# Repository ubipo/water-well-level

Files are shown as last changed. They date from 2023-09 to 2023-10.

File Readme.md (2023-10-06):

# Water Well Level 🛜📏🪣💦

**Ultrasonic IoT sensor to measure water level in a well**

My dad and I needed a way to ensure the water level in a rain water collection
well doesn't drop too low and that a pump actually uses the water as scheduled.
So, as a fun end-to-end IoT project, I put together a sensor, serverless
backend, and web UI.

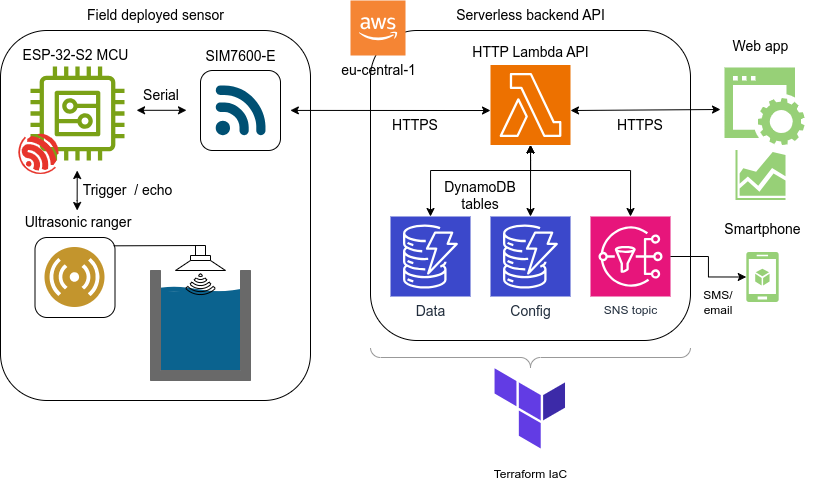
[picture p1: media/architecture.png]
Architecture


## Sensor

The field-deployed sensor uses a
[hc-sr04](https://www.velleman.eu/products/view/?id=463692)-like ultrasonic
ranger to measure the water level from above. The measurements from this are
collected by an [ESP32-S2](https://www.sparkfun.com/products/17743) WiFi microcontroller.
Because we don't - yet - have WiFi available though, I also added a
[SIM7600E](https://simcom.ee/modules/lte/sim7600e/) cellular breakout board with
a prepaid SIM. The microcontroller is programmed in C++ using the
[PlatformIO](https://platformio.org/) toolchain. This entire system is powered by two 2500
mAh @ 3.7 V LiPo
batteries for a battery life of hopefully at least ~3 weeks @ 1
measurement/hour.

## Serverless backend

The sensor periodically sends its measurements and remaining battery capacity to
a serverless HTTPS API deployed to [AWS Lambda](https://aws.amazon.com/lambda/).
The lambda then saves these measurements to a
[DynamoDB](https://aws.amazon.com/dynamodb/) table and notifies an
[SNS](https://aws.amazon.com/sns/) topic for SMS and email notifications. It
also has an endpoint to query the table and to save and retrieve configuration
values. This cloud infrastructure is all defined and deployed as
[Terraform](https://www.terraform.io/) code.

## Web UI

Finally, a [Svelte](https://svelte.dev/) web app hosted on GitHub pages queries the lambda backend and presents the data in a graph using
[Chart.js](https://www.chartjs.org/). The app also allows you to configure the
sensor remotely.

## Images

<figure>
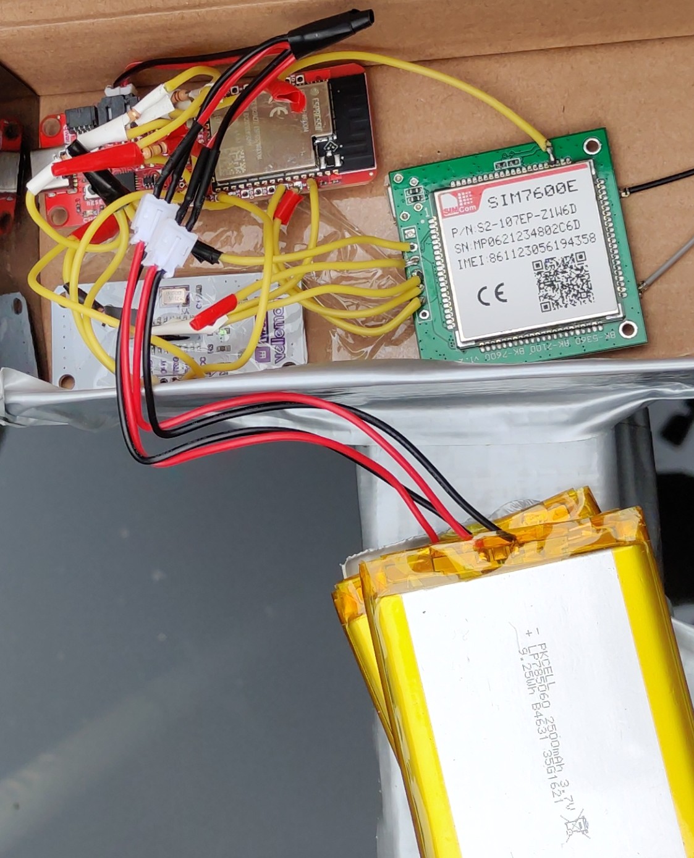
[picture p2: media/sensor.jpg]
Sensor
  
  <figcaption style="text-align: center; font-style: italic;">
    The sensor with white ultrasonic ranger, green SIM7600E cellular breakout board, and red ESP32-S2 microcontroller.
  </figcaption>
</figure>

<figure>
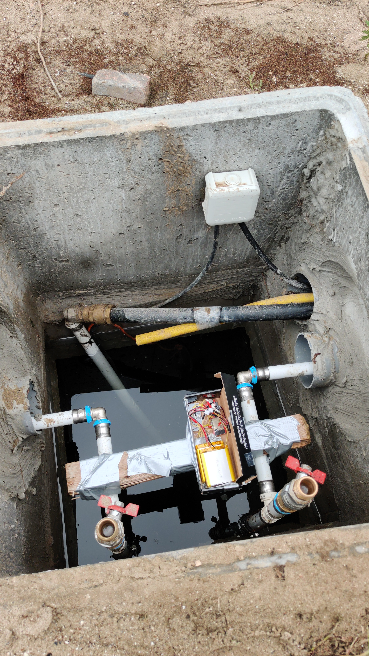
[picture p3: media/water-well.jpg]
Water well
  
  <figcaption style="text-align: center; font-style: italic;">
    The water well with the sensor - for now - attached to pvc pipes.
  </figcaption>
</figure>

<figure>
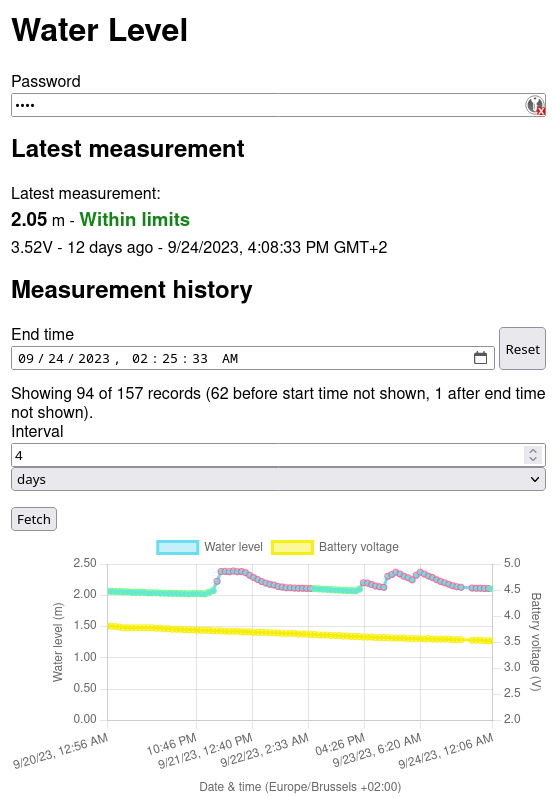
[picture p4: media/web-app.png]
Web app
  
  <figcaption style="text-align: center; font-style: italic;">
    The web app showing the water level and battery voltage over time.
  </figcaption>
</figure>

<figure>
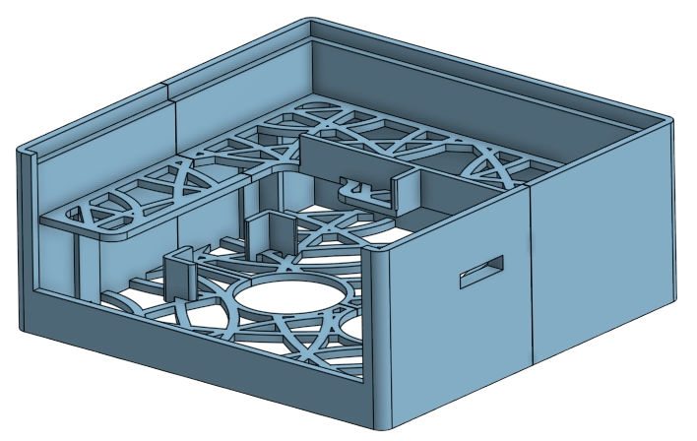
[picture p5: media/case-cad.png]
Case CAD design
  
  <figcaption style="text-align: center; font-style: italic;">
    CAD model of the case for the sensor with snap close tabs. I haven't been able to produce a proper print yet due to bed adhesion issues.
  </figcaption>
</figure>

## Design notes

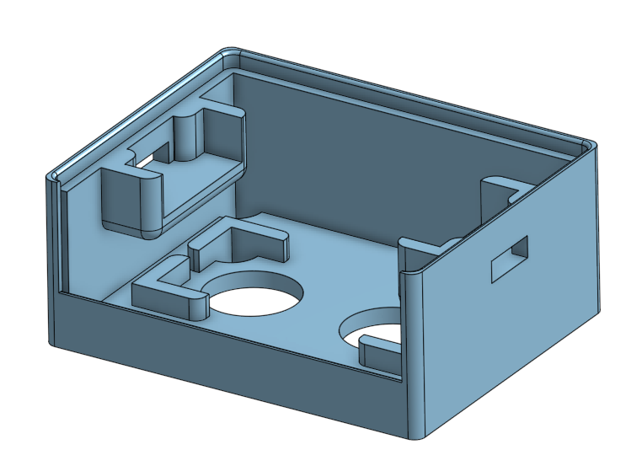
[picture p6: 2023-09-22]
v1-solid/main.png

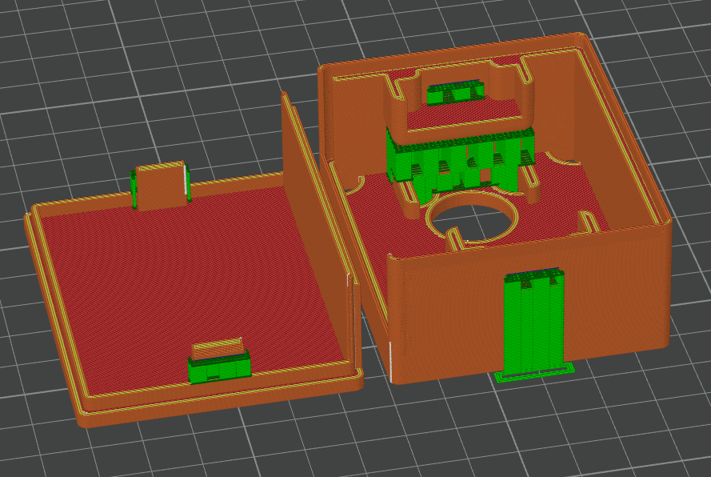
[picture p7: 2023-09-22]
v1-solid/sliced.png

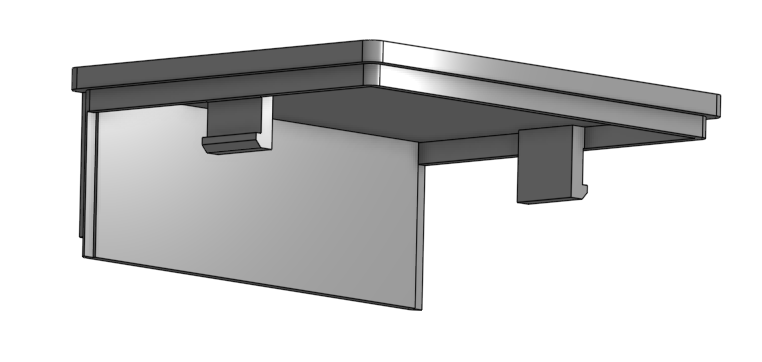
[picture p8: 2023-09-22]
v1-solid/cover.png

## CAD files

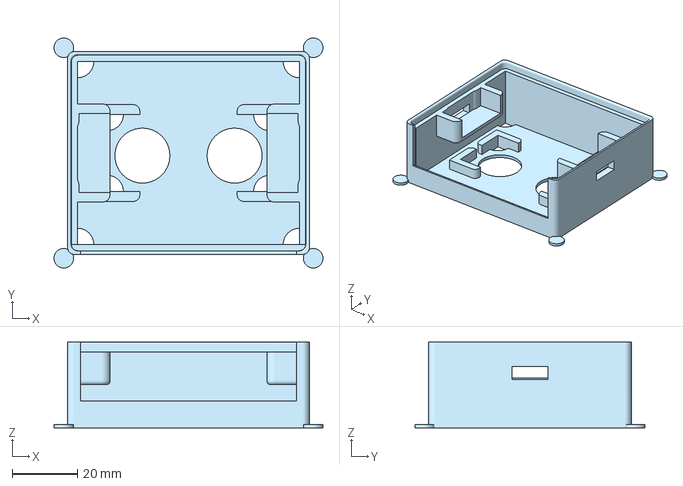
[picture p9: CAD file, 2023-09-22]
v1-solid/waterput-projectdoos-main.3mf
82.3 x 70.4 x 26.2 mm

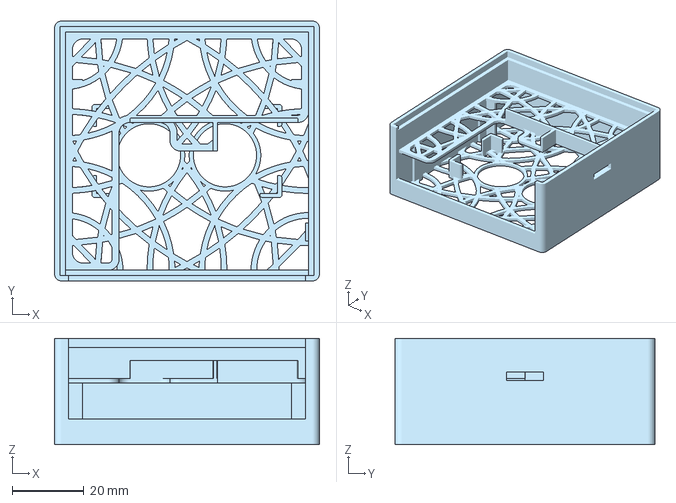
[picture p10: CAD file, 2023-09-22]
v2-pattern/waterput-projectdoos-main.3mf
73.9 x 72.5 x 29.6 mm

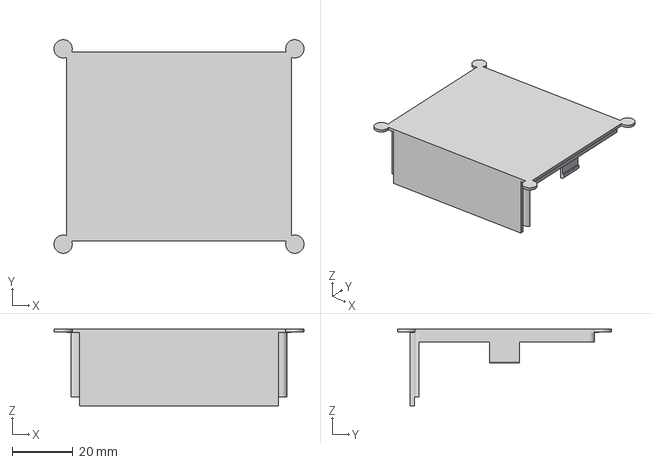
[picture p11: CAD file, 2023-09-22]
v1-solid/waterput-projectdoos-cover.3mf
82.0 x 70.1 x 25.2 mm

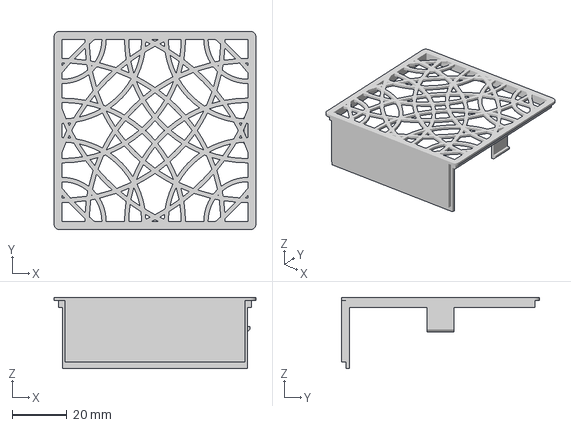
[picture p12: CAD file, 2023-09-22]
v2-pattern/waterput-projectdoos-lid.3mf
73.9 x 72.5 x 26.1 mm

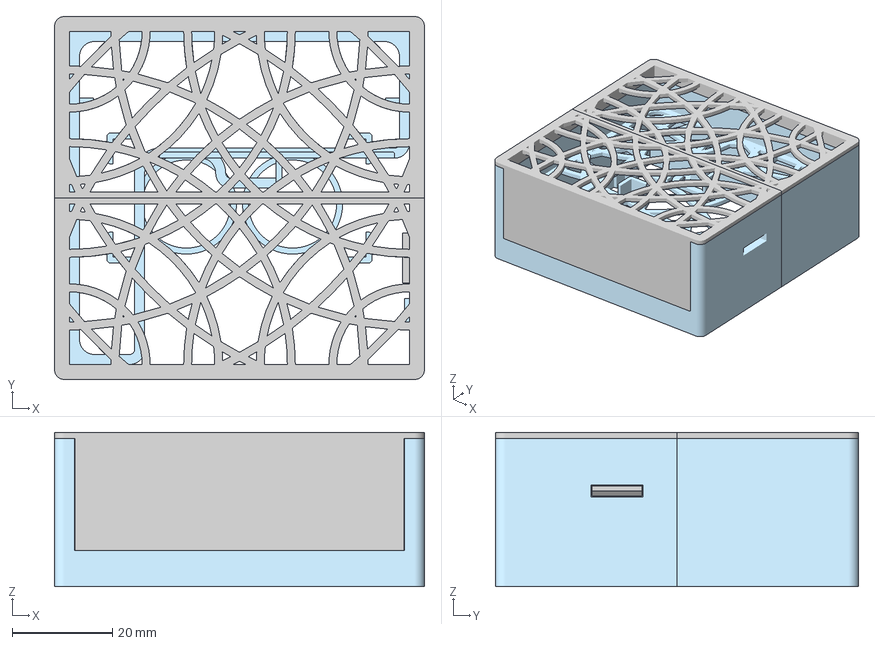
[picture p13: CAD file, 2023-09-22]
v3-pattern-split/water-level-projectdoos.3mf
73.9 x 72.5 x 30.8 mm
main F
lid F
main B
lid B

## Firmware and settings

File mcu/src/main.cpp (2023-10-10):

#include <Arduino.h>
#include <LittleFS.h>
#include "common_macros.h"
#include "cellular.h"
#include "http.h"
#include "distance_sensor.h"
#include "fast_blink.h"
#include "stream_extensions.h"
#include <ArduinoJson.h>
#include "build_time.h"
#include "api_secrets.h"


/// Pins
#define PIN_BATTERY_VOLTAGE_DIVIDER A3
#define PIN_USB_VOLTAGE_DIVIDER A2

/// Params
#define BATTERY_VOLTAGE_DIVIDER_RATIO 2.0
#define USB_VOLTAGE_DIVIDER_RATIO (1.0+2.2)
#define BATTER_CUTOFF_VOLTAGE 3.5
#define MAXIMUM_INTER_TRANSMIT_DISTANCE_MM 30
// In other words: maximum number of measurements to send in batch
#define MAXIMUM_INTER_TRANSMIT_MEASUREMENTS 30
#define MAXIMUM_INTER_TRANSMIT_TIME_S 60 * 60 * 24


bool timeIsSet() {
  time_t now = time(nullptr);
  return now > BUILD_TIME_UNIX_S;
}

void setupVoltageDividers() {
  pinMode(PIN_BATTERY_VOLTAGE_DIVIDER, INPUT);
  pinMode(PIN_USB_VOLTAGE_DIVIDER, INPUT);
}

double adcValueToVoltage(uint16_t adcValue, double voltageDividerRatio) {
  // ADC_ATTEN_DB_11
  // https://docs.espressif.com/projects/esp-idf/en/v4.4.2/esp32s2/api-reference/peripherals/adc.html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
  return adcValue * (2.5 / 8191.0) * voltageDividerRatio;
}

double getBatteryVoltage() {
  uint16_t voltage_divider_adc = analogRead(PIN_BATTERY_VOLTAGE_DIVIDER);  
  return adcValueToVoltage(voltage_divider_adc, BATTERY_VOLTAGE_DIVIDER_RATIO);
}

double getBatteryVoltageAveraged(unsigned char count) {
  double sum = 0;
  for (unsigned char i = 0; i < count; i++) {
    delay(1);
    sum += getBatteryVoltage();
    delay(9);
  }
  return sum / count;
}

double getUsbVoltage() {
  uint16_t voltage_divider_adc = analogRead(PIN_USB_VOLTAGE_DIVIDER);  
  LOGF("[INF|Main] USB voltage divider ADC value: %d\n", voltage_divider_adc);
  return adcValueToVoltage(voltage_divider_adc, USB_VOLTAGE_DIVIDER_RATIO);
}

double getUsbVoltageAveraged(unsigned char count) {
  double sum = 0;
  for (unsigned char i = 0; i < count; i++) {
    delay(1);
    sum += getUsbVoltage();
    delay(9);
  }
  return sum / count;
}

unsigned char batteryVoltageToPercentage(double voltage) {
  double voltages[] = {
    4.17, 4.15, 4.10, 4.05, 4.00, 3.93, 3.85, 3.84, 3.83, 3.81, 3.80, 3.79, 3.75,
    3.70, 3.65, 3.35
  };
  unsigned char percentages[] = {
    100, 95, 89, 83, 75, 65, 50, 46, 42, 40, 36, 30, 25, 11, 5, 2
  };
  for (unsigned char i = 0; i < sizeof(voltages) / sizeof(double); i++) {
    if (voltage > voltages[i]) {
      return percentages[i];
    }
  }
  return 0;
}

const __FlashStringHelper* SAVED_MEASUREMENTS_FILE_PATH = F("/last_measurements.txt");

struct Measurement {
  unsigned long timeS;
  unsigned long distanceMM;
  double batteryVoltage;
};

bool readMeasurementFromFile(File* file, Measurement* measurement) {  
  u_int size = sizeof(Measurement);
  size_t bytesRead = file->readBytes((char*) measurement, size);
  return bytesRead == size;
}

size_t readSavedMeasurements(
  File* file,
  Measurement measurements[],
  size_t maxSavedMeasurements,
  unsigned long* smallestDistance,
  unsigned long* largestDistance
) {
  file->seek(0);
  size_t nbroSavedMeasurements = 0;
  while (
    nbroSavedMeasurements < maxSavedMeasurements
    && readMeasurementFromFile(
      file,
      &measurements[nbroSavedMeasurements]
    )
  ) {
    auto distance = measurements[nbroSavedMeasurements].distanceMM;
    LOGF("[INF|Main] Saved measurement %d: %d mm\n", nbroSavedMeasurements, distance);
    if (distance < *smallestDistance) {
      *smallestDistance = distance;
    }
    if (distance > *largestDistance) {
      *largestDistance = distance;
    }
    nbroSavedMeasurements++;
  }
  return nbroSavedMeasurements;
}

uint8_t transmitMeasurements(Measurement measurements[], size_t nbroMeasurements) {
  LOGLN("[INF|Main] Setting up cellular...");
  setupCellularIO();
  setupCellular();
  LOGLN("[INF|Main] Cellular setup done");

  LOGLN("[INF|Main] Sending HTTP request...");
  Serial1.println("AT+CCHSTART");
  delay(2000);
  while(Serial1.available()) {
    Serial.write(Serial1.read());
  }

  StaticJsonDocument<MAXIMUM_INTER_TRANSMIT_MEASUREMENTS * 64> json;
  
  for (size_t i; i < nbroMeasurements; i++) {
    auto measurement = measurements[i];
    JsonObject measurementJson = json.createNestedObject();
    measurementJson["timeS"] = measurement.timeS;
    measurementJson["distanceMM"] = measurement.distanceMM;
    measurementJson["batteryVoltage"] = measurement.batteryVoltage;
  }

  String jsonString;
  serializeJson(json, jsonString);

  LOGF("[INF|Main] JSON: %s\n", jsonString.c_str());

  String response;
  unsigned long beforeSendMilli = millis();
  uint8_t res = httpPost(
    HTTP_API_BASE_URL "/measurement?"
    // "distanceMM=" + String(currentDistance) +
    // "&batteryVoltage=" + String(batteryVoltage) +
    "token=" HTTP_API_WRITE_TOKEN,
    &jsonString,
    &response,
    10000
  );
  unsigned long afterSendMilli = millis();
  if (res != 0) {
    LOGF("[ERR|Main] HTTP request failed with code %d\n", res);
    return RET_ERROR;
  }

  // Get current time from response
  // Parsing response JSON is a little overkill though
  int nowIndex = response.indexOf("\"now\":");
  int nowEndIndex = _min(
    response.indexOf(",", nowIndex),
    response.indexOf("}", nowIndex)
  );
  String nowString = response.substring(nowIndex + 6, nowEndIndex);
  LOGF("[INF|Main] Got time from response: %s\n", nowString.c_str());
  unsigned long sendDurationMilli = afterSendMilli - beforeSendMilli;
  // Add 1/3 of the send duration to the time because time being a bit late is
  // better than too early
  time_t now = atol(nowString.c_str()) + (sendDurationMilli / 3);
  LOGF("[INF|Main] Setting time to %d\n", now);
  timeval tv = { .tv_sec = now, .tv_usec = 0 };
  settimeofday(&tv, DST_NONE);

  LOGLN("[INF|Main] HTTP request done");
  return RET_OK;
}

void setup() {
  pinMode(LED_BUILTIN, OUTPUT);
  Serial.begin(9600);
  Serial.println("");

  fastBlink(1);

  esp_reset_reason_t reset_reason = esp_reset_reason();
  if (reset_reason == ESP_RST_DEEPSLEEP) {
    LOGLN("[INF|Main] Reset reason: deep sleep");
  } else if (reset_reason == ESP_RST_PANIC) {
    LOGLN("[WRN|Main] Reset reason: panic");
  } else {
    LOGF("[INF|Main] Reset reason: %d\n", reset_reason);
  }

  setupVoltageDividers();

  double usbVoltage = getUsbVoltageAveraged(3);
  LOGF("[INF|Main] USB voltage: %f\n", usbVoltage);
  if (usbVoltage > 4.0) {
    LOGF("[INF|Main] USB power connected, voltage: %f\n", usbVoltage);
    bool cellularIsOn = false;
    checkIfCellularIsOn(5000, &cellularIsOn);
    if (cellularIsOn) {
      LOGF("[INF|Main] Cellular is on. Powering cellular off...\n");
      powerOffCellular();
    }
    LOGF("[INF|Main] Staying awake to charge battery...\n");
    return;
  }

  delay(2);
  double batteryVoltage = getBatteryVoltageAveraged(5);
  unsigned char batteryPercentage = batteryVoltageToPercentage(batteryVoltage);
  LOGF(
    "[INF|Main] Battery voltage: %f, percentage estimate: %d\n",
    batteryVoltage, batteryPercentage
  );
  if (batteryVoltage < BATTER_CUTOFF_VOLTAGE) {
    LOGF(
      "[INF|Main] Battery voltage below cutoff (%f < %f), sleeping for 24 hours...\n",
      batteryVoltage, BATTER_CUTOFF_VOLTAGE
    );
    esp_sleep_enable_timer_wakeup((uint64_t) 24 * 60 * 60 * 1000000);
    esp_deep_sleep_start();
  }

  setupDistanceSensor();

  time_t measurementTime = time(nullptr);
  unsigned long currentDistance = getDistanceMMAveraged(10);
  LOGF("[INF|Main] Distance: %lu mm, time: %d\n", currentDistance, measurementTime);

  LOGF("[INF|Main] Setting up LittleFS...\n");
  if (!LittleFS.begin()){
    LOGF("[ERR|Main] Failed to mount file system. Trying to format...\n");
    if (!LittleFS.format()) {
      LOGF("[ERR|Main] Failed to format file system. Rebooting...\n");
      // TODO: Handle... somehow
      esp_restart();
    }
  }
  if (reset_reason == ESP_RST_PANIC) {
    LOGLN("[INF|Main] Formatting file system out of precaution because of previous panic reset...");
    if (!LittleFS.format()) {
      LOGF("[ERR|Main] Failed to format file system. Rebooting...\n");
      esp_restart();
    }
  }
  LOGF("[INF|Main] LittleFS setup done\n");

  File savedMeasurementsFile = LittleFS.open(SAVED_MEASUREMENTS_FILE_PATH, "a+", true);
  if (!savedMeasurementsFile) {
    LOGF("[ERR|Main] Failed to open saved measurements file. Rebooting...\n");
    esp_restart();
  }
  LOGF("[INF|Main] Saved measurements file size: %d\n", savedMeasurementsFile.size());
  
  // Not including the current measurement
  const auto maxCachedMeasurements = MAXIMUM_INTER_TRANSMIT_MEASUREMENTS - 1;
  auto savedMeasurements = new Measurement[MAXIMUM_INTER_TRANSMIT_MEASUREMENTS];
  
  savedMeasurements[0] = {
    .timeS = static_cast<unsigned long>(measurementTime),
    .distanceMM = currentDistance,
    .batteryVoltage = batteryVoltage
  };
  auto smallestDistance = currentDistance;
  auto largestDistance = currentDistance;
  auto nbroSavedMessages = readSavedMeasurements(
    &savedMeasurementsFile,
    &savedMeasurements[1],
    MAXIMUM_INTER_TRANSMIT_MEASUREMENTS,
    &smallestDistance,
    &largestDistance
  );

  LOGF("[INF|Main] Read %d saved measurements from file\n", nbroSavedMessages);

  auto nbroMessagesToTransit = nbroSavedMessages + 1;

  unsigned long timeOfOldestMeasurement = savedMeasurements[0].timeS;
  unsigned long distanceDelta = _max(
    _abs(currentDistance - smallestDistance),
    _abs(currentDistance - largestDistance)
  );

  LOGF("[INF|Main] Checking if we should transmit...\n");
  bool shouldTransmit = false;
  if (nbroMessagesToTransit >= MAXIMUM_INTER_TRANSMIT_MEASUREMENTS) {
    LOGF("[INF|Main] Transmitting because we have %d measurements (> %d)\n", nbroMessagesToTransit, MAXIMUM_INTER_TRANSMIT_MEASUREMENTS);
    shouldTransmit = true;
  } else if (
    distanceDelta > MAXIMUM_INTER_TRANSMIT_DISTANCE_MM
  ) {
    LOGF("[INF|Main] Transmitting because distance delta is %d mm (> %d)\n", distanceDelta, MAXIMUM_INTER_TRANSMIT_DISTANCE_MM);
    shouldTransmit = true;
  } else if (!timeIsSet()) {
    LOGF("[INF|Main] Transmitting because time is not set\n");
    shouldTransmit = true;
  } else if (millis() > MAXIMUM_INTER_TRANSMIT_TIME_S * 1000) {
    LOGF("[INF|Main] Transmitting because we have been awake for %d seconds (> %d)\n", millis() / 1000, MAXIMUM_INTER_TRANSMIT_TIME_S);
    shouldTransmit = true;
  } else {
    LOGLN("[INF|Main] No need to transmit, saving measurement to flash instead");
  }

  if (shouldTransmit) {
    Serial.println("Transmitting...");
    transmitMeasurements(savedMeasurements, nbroMessagesToTransit);

    LOGF("[INF|Main] Clearing saved measurements file...\n");
    savedMeasurementsFile.close();
    LittleFS.remove(SAVED_MEASUREMENTS_FILE_PATH);

    LOGLN("[INF|Main] Powering off cellular...");
    powerOffCellular();

    for (int i = 0; i < 3; i++) {
      fastBlink(5);
      delay(1000);
    }
  } else {
    Serial.println("Not transmitting");
    LOGF("[INF|Main] Not transmitting\n");
    LOGF("[INF|Main] Saving measurement to file (%d MM, %d S)...\n", currentDistance, measurementTime);
    savedMeasurementsFile.close();
    savedMeasurementsFile = LittleFS.open(SAVED_MEASUREMENTS_FILE_PATH, "a", true);
    savedMeasurementsFile.write((const uint8_t*) &savedMeasurements[0], sizeof(Measurement));
    savedMeasurementsFile.flush();
    savedMeasurementsFile.close();
  }
  LittleFS.end();

  while (true) {
    bool cellularIsOn = false;
    uint32_t cellularOnCheckTimeout = shouldTransmit ? 10000 : 2000;
    checkIfCellularIsOn(cellularOnCheckTimeout, &cellularIsOn);
    if (cellularIsOn) {
      LOGF("[ERR|Main] Cellular is still on. Trying again to turn off...\n");
      powerOffCellular();
      delay(2000);
    } else {
      LOGLN("[INF|Main] Confirmed cellular is off.");
      break;
    }
  }

  unsigned long sleepTimeS = 60 * 60;
  // unsigned long sleepTimeS = 10;
  LOGF("[INF|Main] Getting sleepy... Dozing off for %d seconds...\n", sleepTimeS);
  esp_sleep_enable_timer_wakeup((uint64_t) sleepTimeS * 1000000);
  esp_deep_sleep_start();
}

void loop() {
  if (Serial.available()) {
    String line;
    readLine(&Serial, &line);
    if (line == ">sms") {
      // sendSMS();
    } else if (line == ">http") {
      // httpGetDemo();
    } else if (line == ">off") {
      Serial.println("Powering off modem...");
      powerOffCellular();
    } else if (line == ">on") {
      Serial.println("Powering on modem...");
      powerOnCellular();
    } else if (line == ">0") {
      Serial.println("Setting POWERKEY to LOW");
      digitalWrite(PIN_CELLULAR_PWR, LOW);
    } else if (line == ">1") {
      Serial.println("Setting POWERKEY to HIGH");
      digitalWrite(PIN_CELLULAR_PWR, HIGH);
    }

    Serial1.println(line);
  }

  if (Serial1.available()) {
    Serial.write(Serial1.read());
  }
}

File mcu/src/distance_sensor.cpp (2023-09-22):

#include <Arduino.h>
#include "common_macros.h"


#define PIN_TRIGGER A5
#define PIN_ECHO A4

#define DISTANCE_CORRECTION 0.0

void setupDistanceSensor() {
  pinMode(PIN_TRIGGER, OUTPUT);
  pinMode(PIN_ECHO, INPUT);
}

unsigned long getPulseTime() {
  digitalWrite(PIN_TRIGGER, LOW);
  delayMicroseconds(2);
  digitalWrite(PIN_TRIGGER, HIGH);
  delayMicroseconds(10);
  digitalWrite(PIN_TRIGGER, LOW);
  return pulseIn(PIN_ECHO, HIGH);
}

unsigned long getDistanceMM() {
  unsigned long pulseTime = getPulseTime();
  unsigned long distance = ((pulseTime * 0.344) / 2) + DISTANCE_CORRECTION;
  return distance;
}

unsigned long getDistanceMMAveraged(
    unsigned char count
) {
  unsigned long long sum = 0;
  for (unsigned char i = 0; i < count; i++) {
    sum += getDistanceMM();
    delay(10);
  }
  return sum / count;
}
